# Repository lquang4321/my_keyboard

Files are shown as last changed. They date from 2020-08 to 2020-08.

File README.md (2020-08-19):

# Keypad
A standard 17-key numpad in 5x4 config, num lock indicator LED, and a media volume knob. An Arduino Pro Micro (Atmega32u4 5V 16Mhz) is used as the MCU. 
* Author: [Quang Truong](https://github.com/lquang4321) 
* Version: 1 

Make example: 

    make my_keyboard:default
# Schematic
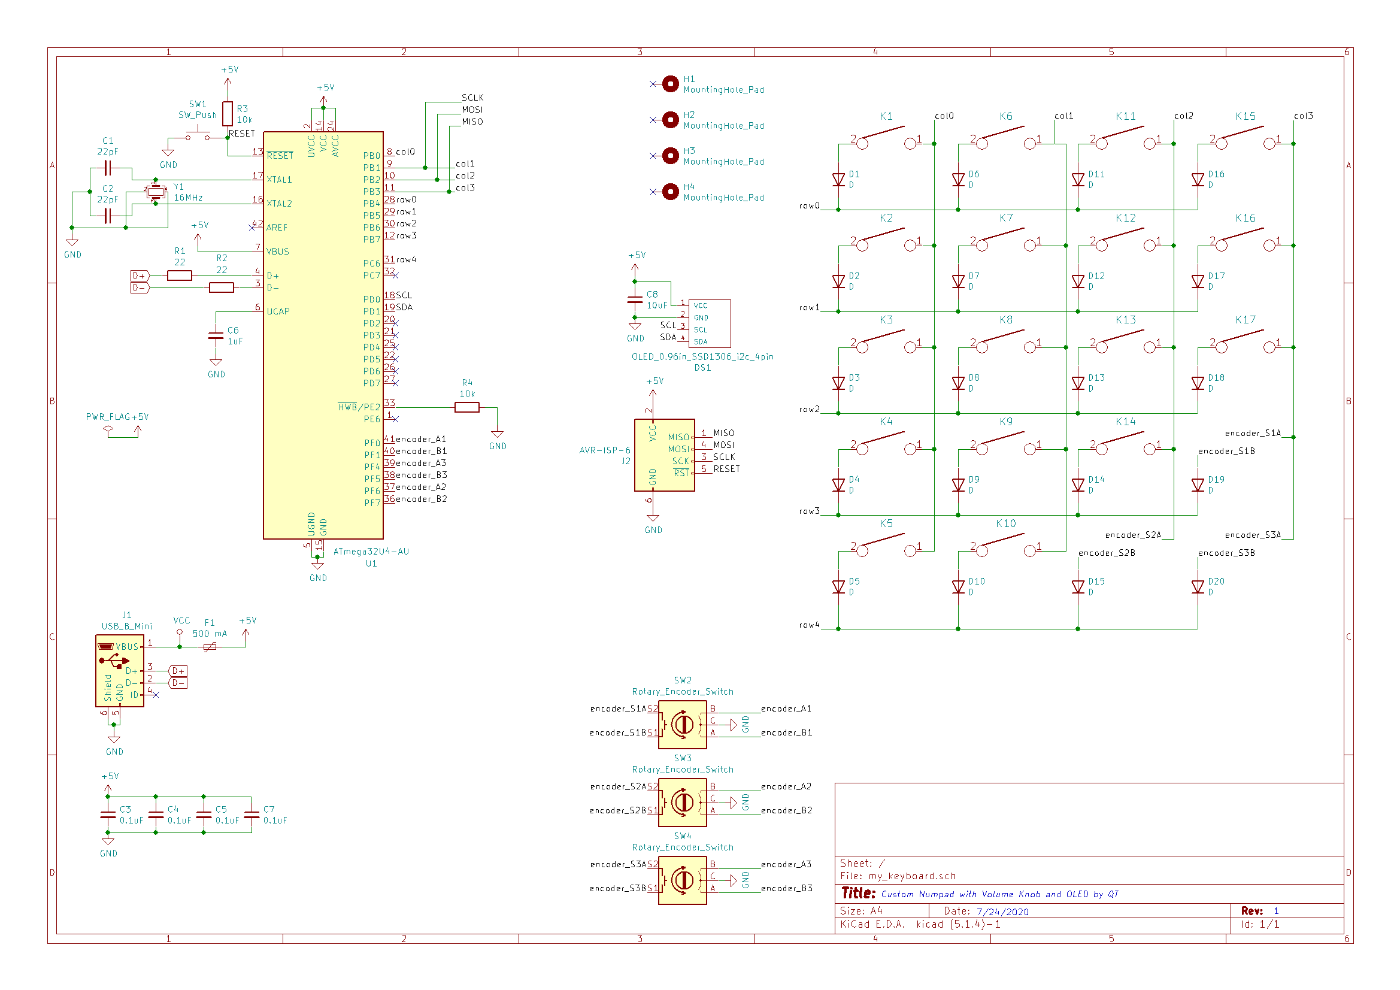
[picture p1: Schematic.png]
GitHub Logo


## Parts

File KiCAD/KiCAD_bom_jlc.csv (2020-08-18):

Comment | Designator | Footprint | LCSC Part #
22pF | C1,C2 | C_0805_2012Metric_Pad1.15x1.40mm_HandSolder | C14663
0.1uF | C3,C4,C5,C7 | C_0805_2012Metric_Pad1.15x1.40mm_HandSolder | C14663
1uF | C6 | C_0805_2012Metric_Pad1.15x1.40mm_HandSolder | C15849
10uF | C8 | C_0805_2012Metric_Pad1.15x1.40mm_HandSolder | C19702
D | D1,D16,D11,D6,D17,D12,D7,D2,D18,D13,D8,D3,D19,D14,D9,D4,D20,D15,D10,D5 | D_SOD-123 | C81598
500 mA | F1 | Fuse_1206_3216Metric_Pad1.42x1.75mm_HandSolder | C151162
22 | R1,R2 | R_0805_2012Metric_Pad1.15x1.40mm_HandSolder | C23345
10k | R4,R3 | R_0805_2012Metric_Pad1.15x1.40mm_HandSolder | C25804
SW_Push | SW1 | SW_PUSH_4_5.1x5.1mm | C318884
ATmega32U4-AU | U1 | TQFP-44_10x10mm_P0.8mm | C44854
16MHz | Y1 | Crystal_SMD_3225-4Pin_3.2x2.5mm_HandSoldering | C13738

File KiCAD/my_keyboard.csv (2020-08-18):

Id | Designator | Package | Quantity | Designation | Supplier and ref
1 | K17,K16 | SW_Cherry_MX_2.00u_Vertical_Plate | 2 | KEYSW
2 | K5 | SW_Cherry_MX_2.00u_Plate | 1 | KEYSW
3 | C6 | C_0805_2012Metric_Pad1.15x1.40mm_HandSolder | 1 | 1uF
4 | DS1 | OLED_0.96in_SSD1306_i2c_4pin | 1 | OLED_0.96in_SSD1306_i2c_4pin
5 | K1,K2,K3,K4,K6,K7,K8,K9,K10,K11,K12,K13,K14,K15 | SW_Cherry_MX_1.00u_PCB | 14 | KEYSW
6 | SW2,SW3,SW4 | RotaryEncoder_Alps_EC11E-Switch_Vertical_H20mm | 3 | Rotary_Encoder_Switch
7 | SW1 | SW_PUSH_4_5.1x5.1mm | 1 | SW_Push
8 | C3,C4,C5,C7 | C_0805_2012Metric_Pad1.15x1.40mm_HandSolder | 4 | 0.1uF
9 | C1,C2 | C_0805_2012Metric_Pad1.15x1.40mm_HandSolder | 2 | 22pF
10 | C8 | C_0805_2012Metric_Pad1.15x1.40mm_HandSolder | 1 | 10uF
11 | F1 | Fuse_1206_3216Metric_Pad1.42x1.75mm_HandSolder | 1 | 500 mA
12 | R1,R2 | R_0805_2012Metric_Pad1.15x1.40mm_HandSolder | 2 | 22
13 | R3,R4 | R_0805_2012Metric_Pad1.15x1.40mm_HandSolder | 2 | 10k
14 | U1 | TQFP-44_10x10mm_P0.8mm | 1 | ATmega32U4-AU
15 | Y1 | Crystal_SMD_3225-4Pin_3.2x2.5mm_HandSoldering | 1 | 16MHz
16 | H1,H2,H3,H4 | MountingHole_3.2mm_M3_Pad_Via | 4 | MountingHole_Pad
17 | J1 | Molex-0548190589 | 1 | USB_B_Mini
18 | D1,D2,D3,D4,D5,D6,D7,D8,D9,D10,D11,D12,D13,D14,D15,D16,D17,D18,D19,D20 | D_SOD-123 | 20 | D

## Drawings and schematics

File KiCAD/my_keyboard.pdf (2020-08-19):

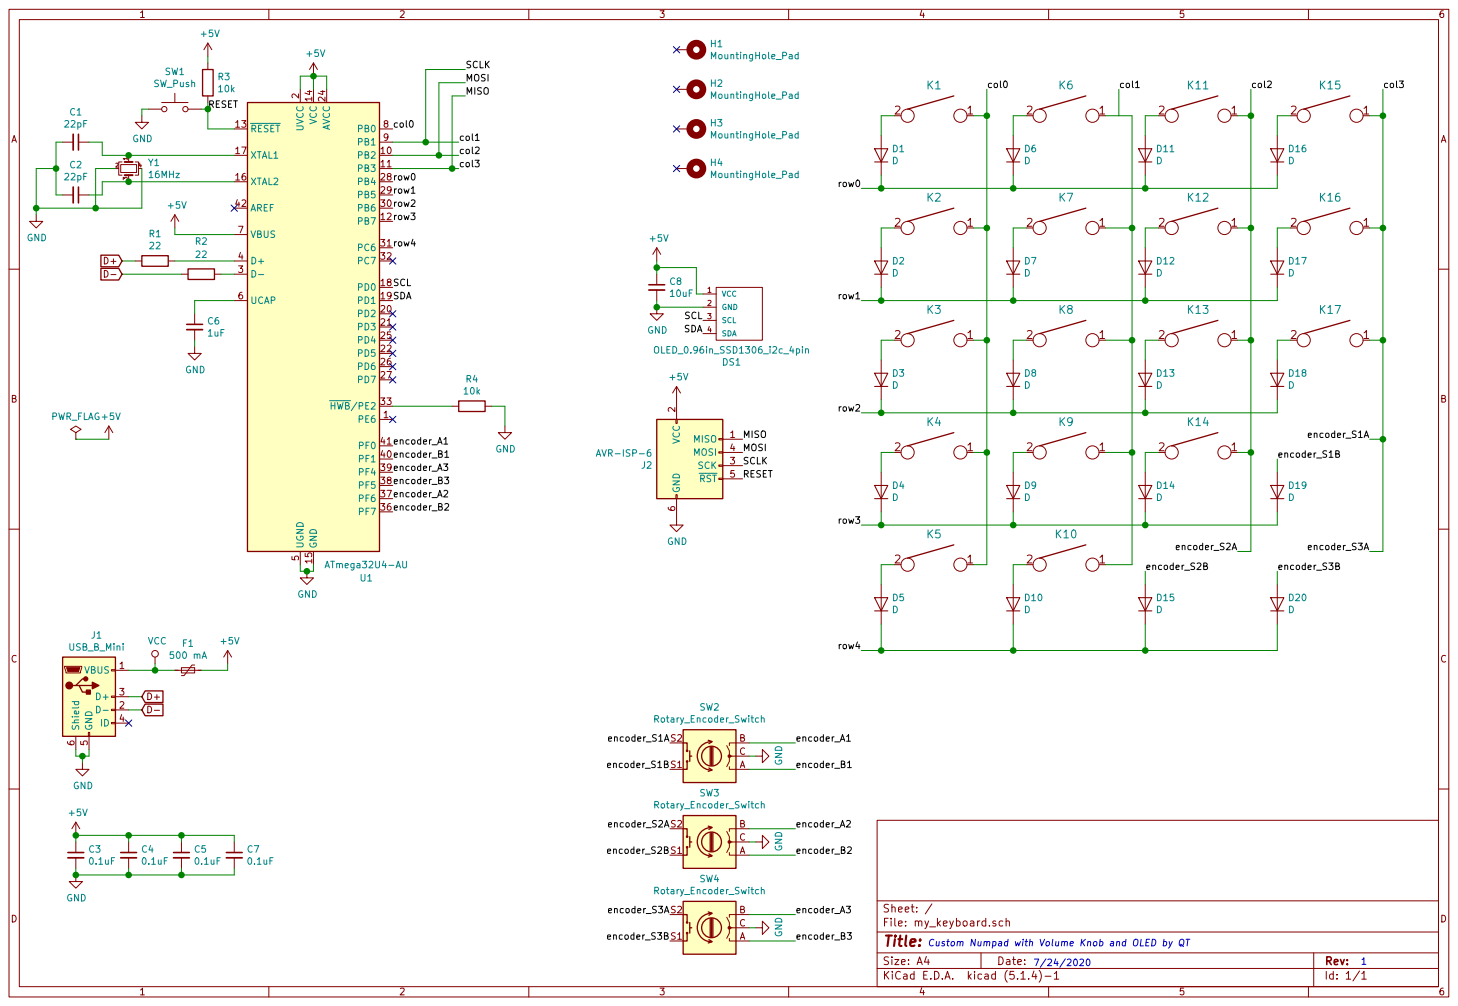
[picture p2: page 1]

2 PD2 20 PD3 21 PD5 22 AVCC 24 PD4 25 PD6 26 PD7 27 PB4 28 PB5 29 D- 3 PB6 30 PC6 31 PC7 32 HWB/PE2 33 PF7 36 PF6 37 PF5 38 PF4 39 D+ 4 PF1 40 PF0 41 AREF 42 UGND

2 SCK 3 MOSI 4 RST 5 GND

1 Custom Numpad with Volume Knob and OLED by QT

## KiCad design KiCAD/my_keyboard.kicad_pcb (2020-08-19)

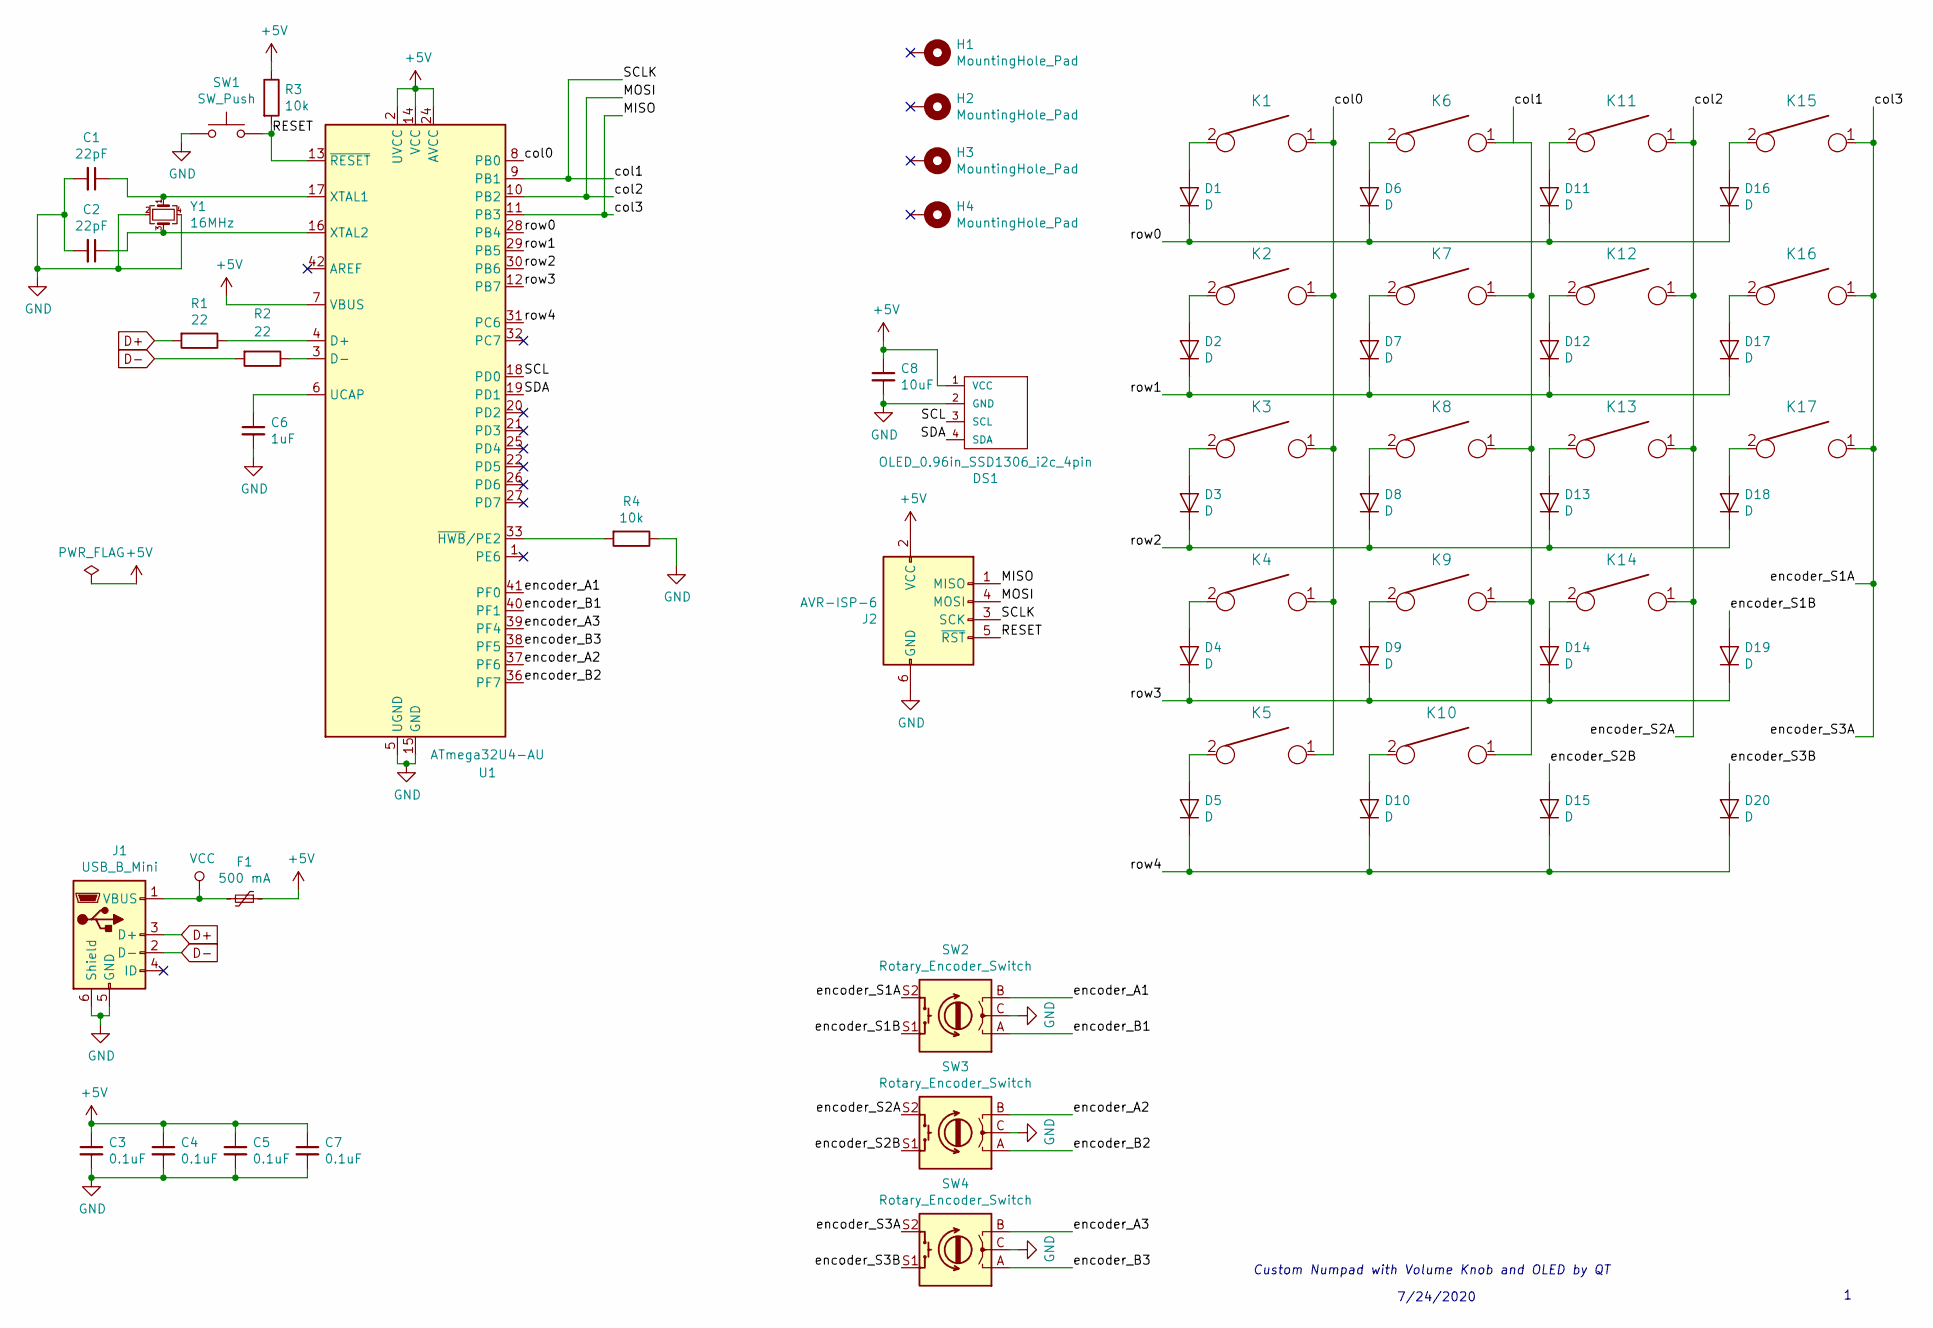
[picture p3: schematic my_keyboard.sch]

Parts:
C1, C2: 22pF; C_0805_2012Metric_Pad1.15x1.40mm_HandSolder; JLCPCB Parts C14663
C3, C4, C5, C7: 0.1uF; C_0805_2012Metric_Pad1.15x1.40mm_HandSolder; JLCPCB Parts C14663
C6: 1uF; C_0805_2012Metric_Pad1.15x1.40mm_HandSolder; JLCPCB Parts C15849
C8: 10uF; C_0805_2012Metric_Pad1.15x1.40mm_HandSolder; JLCPCB Parts C19702
D1, D2, D3, D4, D5, D6, D7, D8, D9, D10, D11, D12, D13, D14, D15, D16, D17, D18, D19, D20: D; D_SOD-123; JLCPCB Parts C81598
DS1: OLED_0.96in_SSD1306_i2c_4pin
F1: 500 mA; Fuse_1206_3216Metric_Pad1.42x1.75mm_HandSolder; JLCPCB Parts C151162
H1, H2, H3, H4: MountingHole_Pad; MountingHole_3.2mm_M3_Pad_Via
J1: USB_B_Mini; USB_miniB
J2: AVR-ISP-6; AVR_ICSP_3x2
K1, K2, K3, K4, K6, K7, K8, K9, K10, K11, K12, K13, K14, K15: KEYSW; SW_Cherry_MX_1.00u_PCB
K5: KEYSW; SW_Cherry_MX_2.00u_Plate
K16, K17: KEYSW; SW_Cherry_MX_2.00u_Vertical_Plate
R1, R2: 22; R_0805_2012Metric_Pad1.15x1.40mm_HandSolder; JLCPCB Parts C23345
R3, R4: 10k; R_0805_2012Metric_Pad1.15x1.40mm_HandSolder; JLCPCB Parts C25804
SW1: SW_Push; SW_PUSH_4_5.1x5.1mm; JLCPCB Parts C318884
SW2, SW3, SW4: Rotary_Encoder_Switch; RotaryEncoder_Alps_EC11E-Switch_Vertical_H20mm
U1: ATmega32U4-AU; TQFP-44_10x10mm_P0.8mm; JLCPCB Parts C44854
Y1: 16MHz; Crystal_SMD_3225-4Pin_3.2x2.5mm_HandSoldering; JLCPCB Parts C13738

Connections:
+5V: C3.1, C4.1, C5.1, C7.1, C8.1, DS1.1 (VCC), F1.1, J2.2 (VCC), R3.1, U1.2 (UVCC), U1.7 (VBUS), U1.14 (VCC), U1.24 (AVCC), U1.34 (VCC), U1.44 (AVCC)
/MISO: J2.1 (MISO), K15.1, K16.1, K17.1, SW2.S2, SW4.S2, U1.11 (PB3)
/MOSI: J2.4 (MOSI), K11.1, K12.1, K13.1, K14.1, SW3.S2, U1.10 (PB2)
/RESET: J2.5 (~RST), R3.2, SW1.2, U1.13 (~RESET)
/SCL: DS1.3 (SCL), U1.18 (PD0)
/SCLK: J2.3 (SCK), K6.1, K7.1, K8.1, K9.1, K10.1, U1.9 (PB1)
/SDA: DS1.4 (SDA), U1.19 (PD1)
/col0: K1.1, K2.1, K3.1, K4.1, K5.1, U1.8 (PB0)
/encoder_A1: SW2.B, U1.41 (PF0)
/encoder_A2: SW3.B, U1.37 (PF6)
/encoder_A3: SW4.B, U1.39 (PF4)
/encoder_B1: SW2.A, U1.40 (PF1)
/encoder_B2: SW3.A, U1.36 (PF7)
/encoder_B3: SW4.A, U1.38 (PF5)
/encoder_S1B: D19.2 (A), SW2.S1
/encoder_S2B: D15.2 (A), SW3.S1
/encoder_S3B: D20.2 (A), SW4.S1
/row0: D1.1 (K), D6.1 (K), D11.1 (K), D16.1 (K), U1.28 (PB4)
/row1: D2.1 (K), D7.1 (K), D12.1 (K), D17.1 (K), U1.29 (PB5)
/row2: D3.1 (K), D8.1 (K), D13.1 (K), D18.1 (K), U1.30 (PB6)
/row3: D4.1 (K), D9.1 (K), D14.1 (K), D19.1 (K), U1.12 (PB7)
/row4: D5.1 (K), D10.1 (K), D15.1 (K), D20.1 (K), U1.31 (PC6)
D+: J1.3 (D+), R1.2
D-: J1.2 (D-), R2.2
GND: C1.2, C2.2, C3.2, C4.2, C5.2, C6.2, C7.2, C8.2, DS1.2 (GND), J1.5 (GND), J1.6 (Shield), J2.6 (GND), R4.1, SW1.1, SW2.C, SW3.C, SW4.C, U1.5 (UGND), U1.15 (GND), U1.23 (GND), U1.35 (GND), U1.43 (GND), Y1.2, Y1.4
unnamed: C1.1, U1.17 (XTAL1), Y1.1
unnamed: C2.1, U1.16 (XTAL2), Y1.3
unnamed: C6.1, U1.6 (UCAP)
unnamed: D1.2 (A), K1.2
unnamed: D2.2 (A), K2.2
unnamed: D3.2 (A), K3.2
unnamed: D4.2 (A), K4.2
unnamed: D5.2 (A), K5.2
unnamed: D6.2 (A), K6.2
unnamed: D7.2 (A), K7.2
unnamed: D8.2 (A), K8.2
unnamed: D9.2 (A), K9.2
unnamed: D10.2 (A), K10.2
unnamed: D11.2 (A), K11.2
unnamed: D12.2 (A), K12.2
unnamed: D13.2 (A), K13.2
unnamed: D14.2 (A), K14.2
unnamed: D16.2 (A), K15.2
unnamed: D17.2 (A), K16.2
unnamed: D18.2 (A), K17.2
unnamed: R1.1, U1.4 (D+)
unnamed: R2.1, U1.3 (D-)
unnamed: R4.2, U1.33 (~HWB~/PE2)
VCC: F1.2, J1.1 (VBUS)

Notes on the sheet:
Custom Numpad with Volume Knob and OLED by QT
7/24/2020

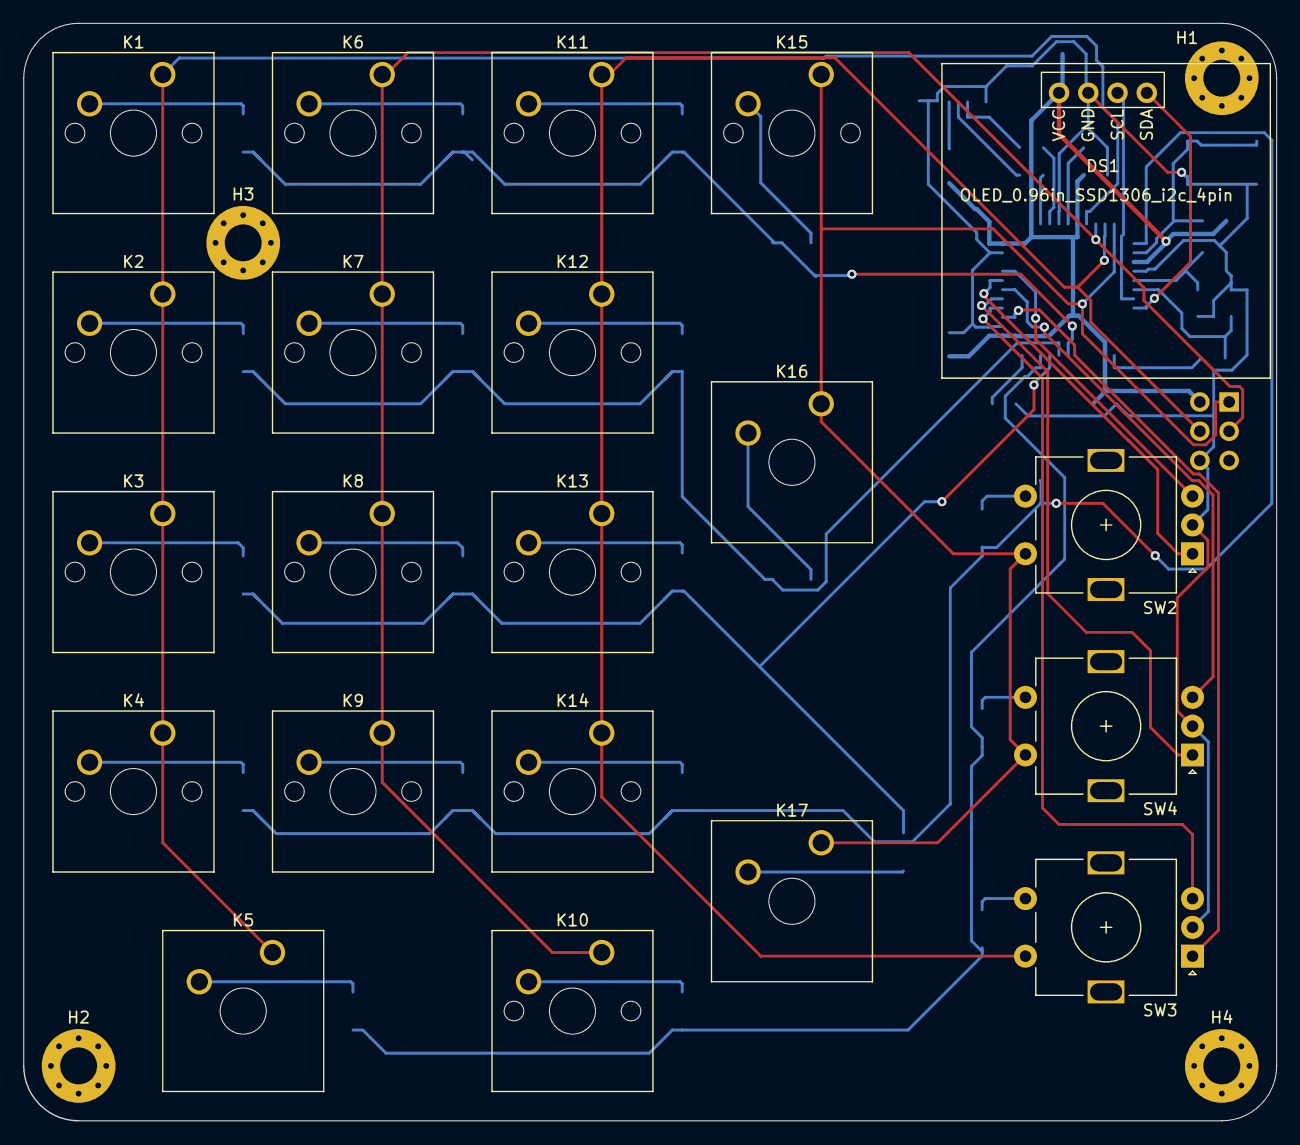
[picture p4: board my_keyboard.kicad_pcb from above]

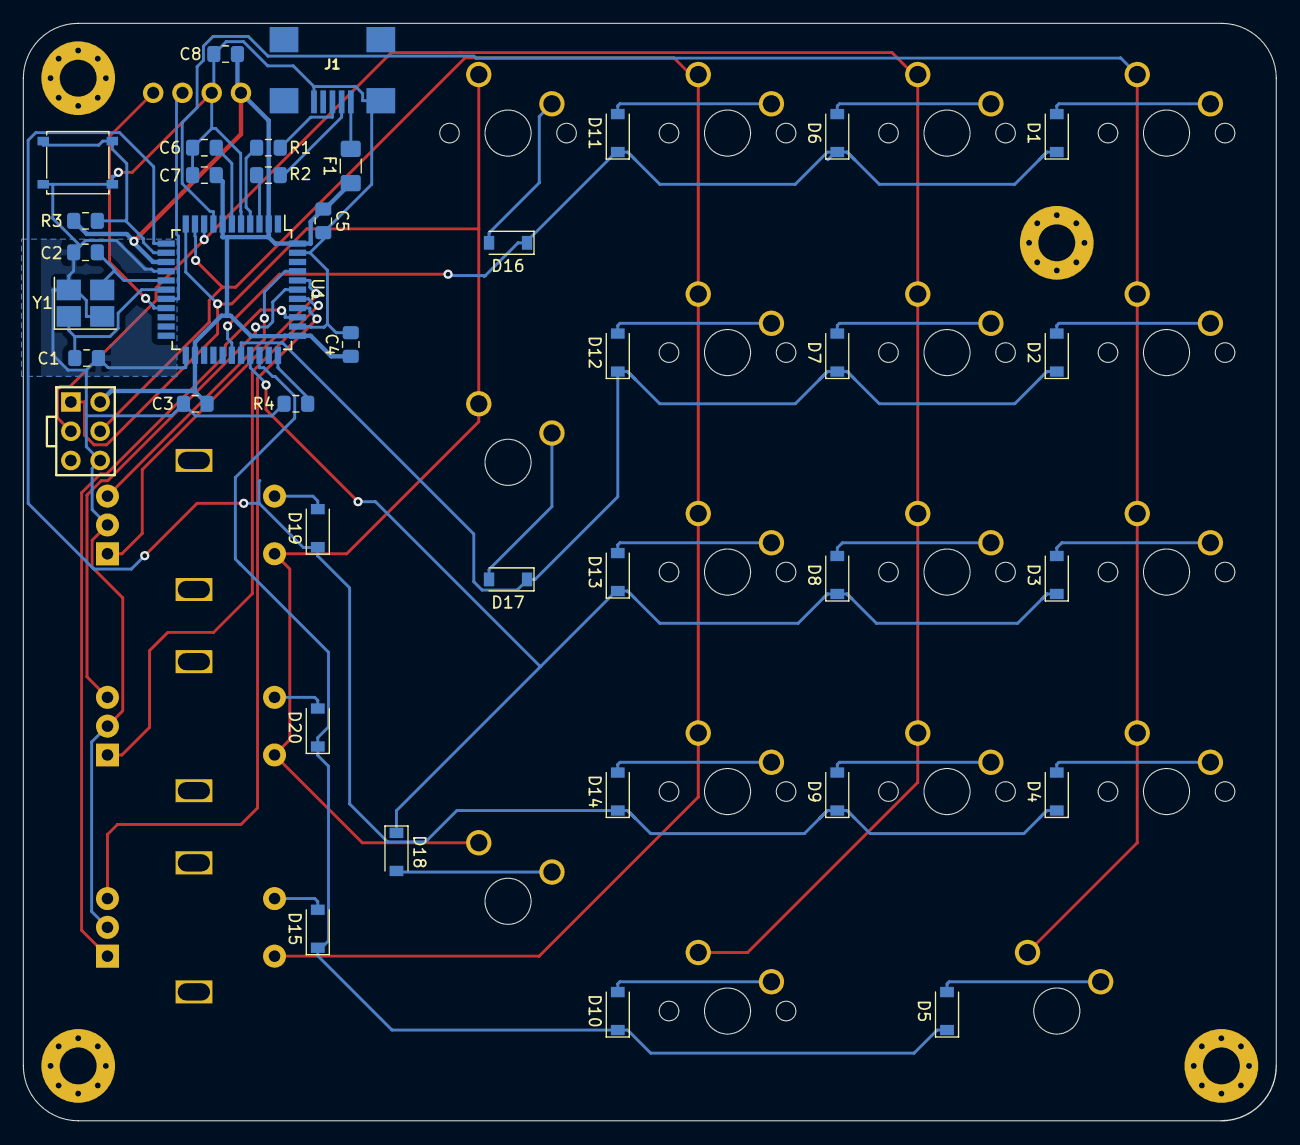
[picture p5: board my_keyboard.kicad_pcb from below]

Board: 2 copper layers, 108.7 x 95.3 mm, 63 parts (38 on the bottom side), 49 nets.

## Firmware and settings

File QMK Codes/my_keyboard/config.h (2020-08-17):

#pragma once

#include "config_common.h"
/* USB Device descriptor parameter */
#define VENDOR_ID       0x5154
#define PRODUCT_ID      0xB00B
#define DEVICE_VER      0x0001
#define MANUFACTURER    Quang T
#define PRODUCT         QT_pie
#define DESCRIPTION     QMK keyboard firmware for handwired numpad with 17 keys and vol knob

/* key matrix size */
#define MATRIX_ROWS 5
#define MATRIX_COLS 4

// ROWS: Top to bottom, COLS: Left to right

#define MATRIX_ROW_PINS { D4, C6, D7, E6, B4 }
#define MATRIX_COL_PINS { B1, B3, B2 , B6 }
#define UNUSED_PINS { B0, D5 }          //B0 and D5 are RX, TX LED respectively.

/* NUMLOCK LED PIN */
//#define NUMLOCK_LED F5

/* OLED SSD1306 128x64 */
#ifdef OLED_DRIVER_ENABLE
  #define OLED_DISPLAY_128X64
  #define OLED_TIMEOUT 180000
#endif

/* COL2ROW or ROW2COL */
#define DIODE_DIRECTION ROW2COL

/*Encoder*/
#ifdef ENCODER_ENABLE
#   define ENCODERS_PAD_A {F4, F6, B0}      //F4 and F5 are the same encoder as the same with F6 and F7, so on...
#   define ENCODERS_PAD_B {F5, F7, D5}
#   define ENCODER_RESOLUTION 4
#endif
/* Set 0 if debouncing isn't needed */
#define DEBOUNCE 5

/* LED related stuff*/
#ifdef BACKLIGHT_ENABLE
#   define BACKLIGHT_PIN B5
#   define BACKLIGHT_LEVELS 3
#endif

#ifdef RGBLIGHT_ENABLE
#    define RGB_DI_PIN F4
#    define RGBLIGHT_EFFECT_BREATHING
#    define RGBLED_NUM 1
#    define RGBLIGHT_HUE_STEP 5
#    define RGBLIGHT_SAT_STEP 7
#    define RGBLIGHT_VAL_STEP 8
#    define RGBLIGHT_SLEEP
#    define RGBLIGHT_LIMIT_VAL 128
#endif

/* Limit USB power consumption */
#define USB_MAX_POWER_CONSUMPTION 500

#define NO_ACTION_MACRO
#define NO_ACTION_FUNCTION
#define NO_ACTION_ONESHOT
#define OLED_FONT_END 127

/* Mechanical locking support. Use KC_LCAP, KC_LNUM or KC_LSCR instead in keymap */
#define LOCKING_SUPPORT_ENABLE
/* Locking resynchronize hack */
#define LOCKING_RESYNC_ENABLE

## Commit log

2020-08-17 Create repository
    [my_keyboard.dsn, my_keyboard.kicad_pcb, my_keyboard.sch]
2020-08-17 Organized Folder
    [my_keyboard.dsn, my_keyboard.kicad_pcb, my_keyboard.sch]
2020-08-18 Update PCB
    [my_keyboard.kicad_pcb, my_keyboard.sch]
2020-08-18 Added KiCAD Library
    [my_keyboard.kicad_pcb]
2020-08-18 Updated KiCAD Lib
2020-08-18 Updated KiCAD Schem
    [my_keyboard.sch]
2020-08-18 Fixed Diode Issue
    Previously used wrong diode symbol meant for simulation not design.
    [my_keyboard.dsn, my_keyboard.kicad_pcb, my_keyboard.sch]
2020-08-18 Finalized Prototype PCB
    Due to the cramp nature around the MCU chip, I resorted to using Freerouting to autoroute all the complexity.
    [my_keyboard.dsn, my_keyboard.kicad_pcb]
2020-08-18 Generated Gerber Files
    [my_keyboard-B_Cu.gbl, my_keyboard-B_Mask.gbs, my_keyboard-B_SilkS.gbo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]
2020-08-18 Renamed due to errors with space
    [my_keyboard-B_Cu.gbl, my_keyboard-B_Mask.gbs, my_keyboard-B_SilkS.gbo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]
2020-08-18 Update stuff
    [KiCAD_bom_jlc.csv, my_keyboard.csv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]
2020-08-19 Added Schematic screenshot
